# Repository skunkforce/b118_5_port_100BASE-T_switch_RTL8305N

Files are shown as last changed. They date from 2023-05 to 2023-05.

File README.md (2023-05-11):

# edgy_board number b118
This design is part of the [edgy board project](https://github.com/skunkforce/edgy_boards). It provides a cheap 5 port 100BASE-T switch.

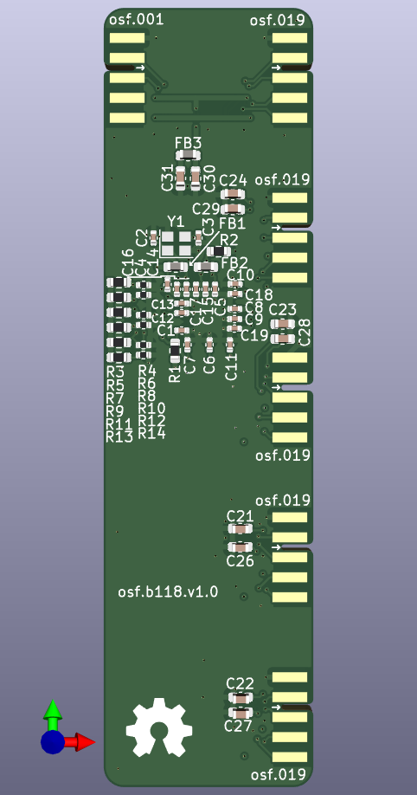
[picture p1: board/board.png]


# getting started
This repository uses submodules. After cloning use the command 

```$ git submodule update --init --recursive```

to pull the submodules before opening the project with kicad. 

# Tests
Tests can be found in [TESTS.md](TESTS.md)

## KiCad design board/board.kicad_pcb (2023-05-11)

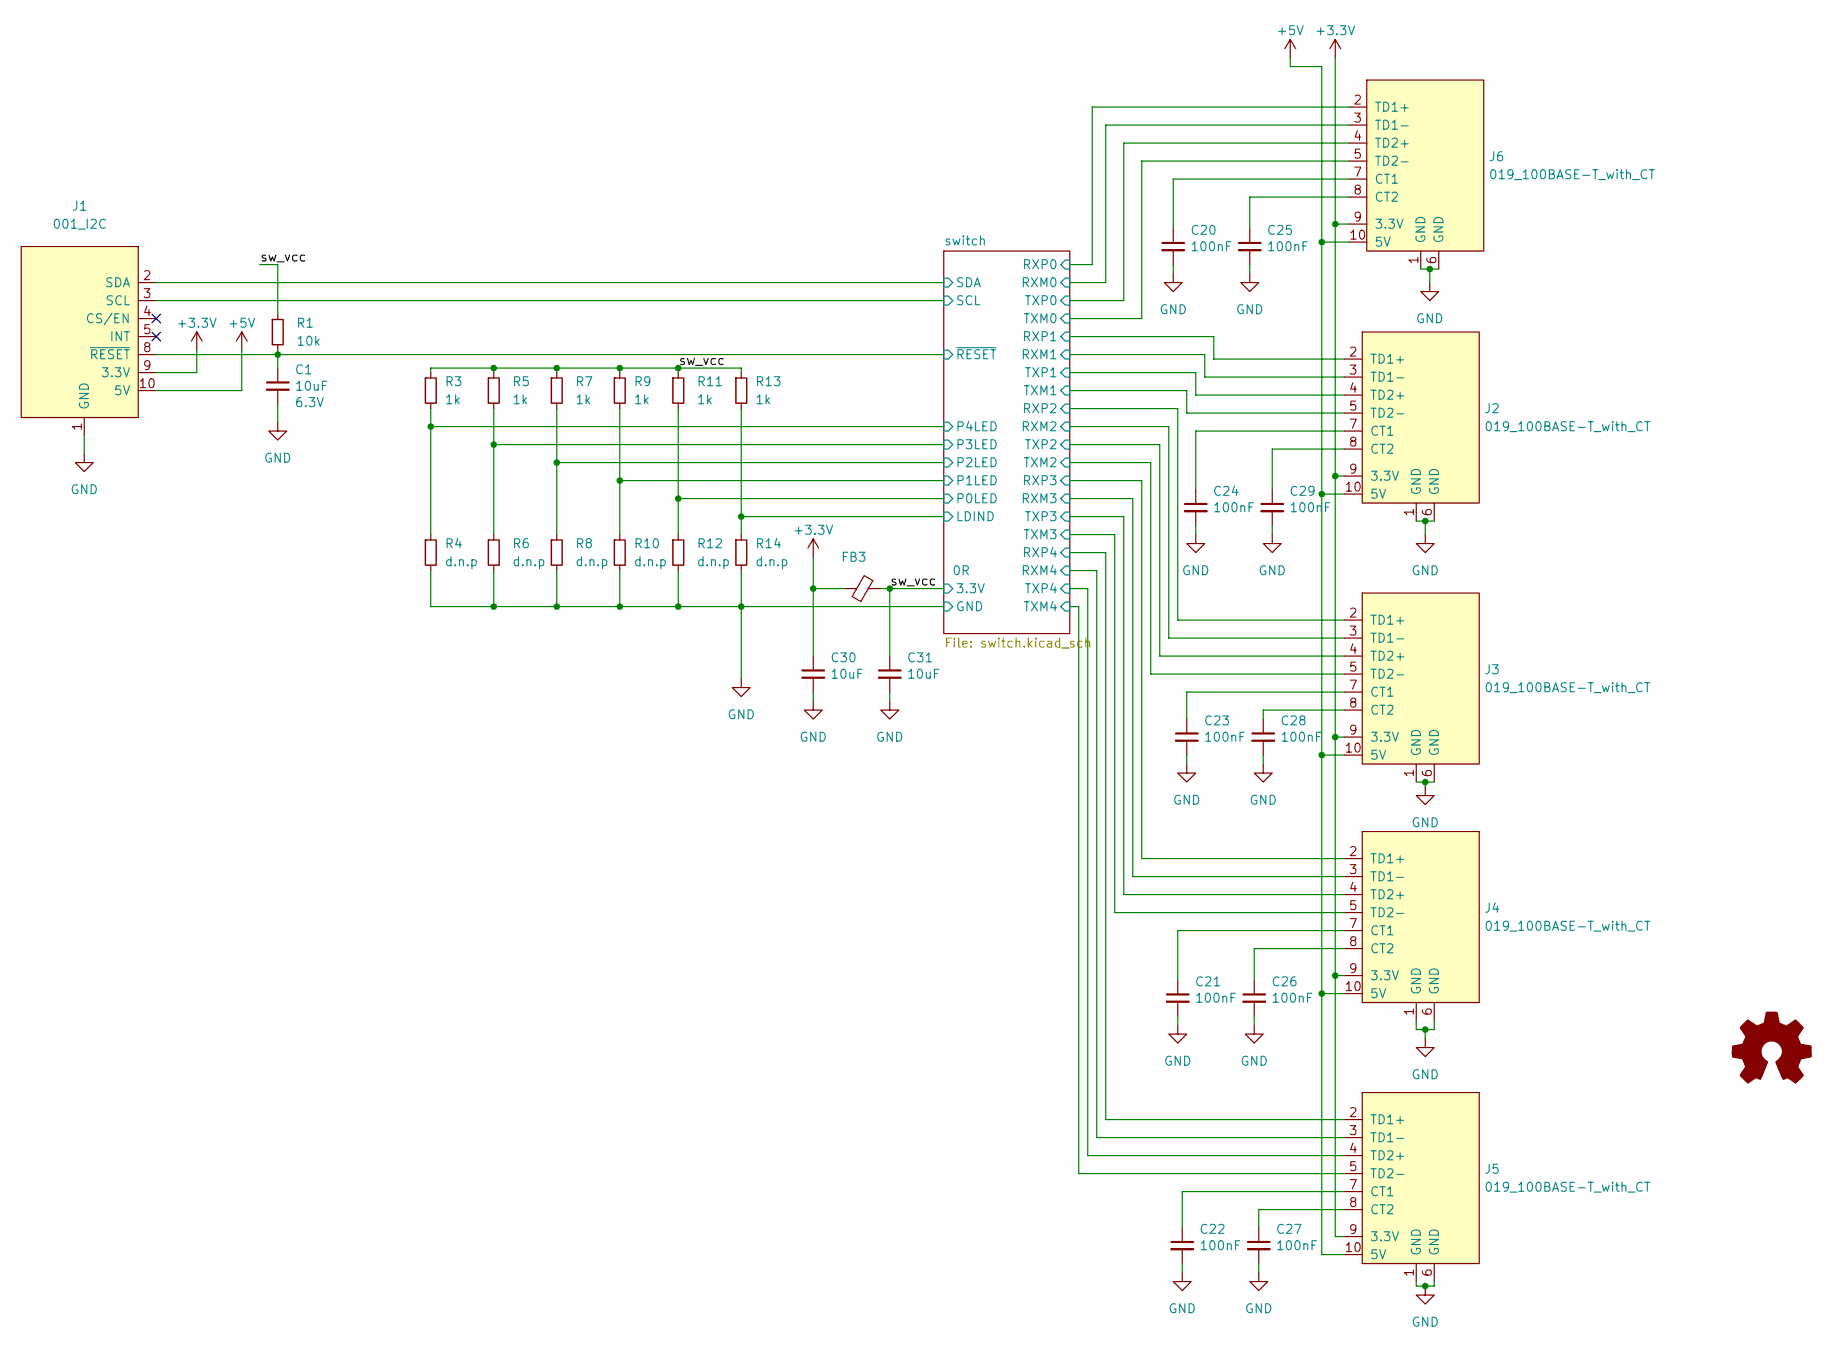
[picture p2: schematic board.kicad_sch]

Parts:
C1: 10uF; C_0402_1005Metric; Voltage 6.3V; MPN CL05A105MP5NNNC; Digi-Key_PN 1276-1448-1-ND
C20, C21, C22, C23, C24, C25, C26, C27, C28, C29: 100nF; C_0603_1608Metric
C30, C31: 10uF; C_0603_1608Metric
FB3: 0R; L_0603_1608Metric; MPN 74279228111
J1: 001_I2C; on_edge_2x05_device
J2, J3, J4, J5, J6: 019_100BASE-T_with_CT; on_edge_2x05_host
LOGO1: Logo_Open_Hardware_Small; OSHW-Symbol_6.7x6mm_SilkScreen
R1: 10k; R_0603_1608Metric
R3, R5, R7, R9, R11, R13: 1k; R_0603_1608Metric
R4, R6, R8, R10, R12, R14: d.n.p; R_0402_1005Metric

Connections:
+3.3V: C30.1, FB3.1, J1.9 (3.3V), J2.9 (3.3V), J3.9 (3.3V), J4.9 (3.3V), J5.9 (3.3V), J6.9 (3.3V)
+5V: J1.10 (5V), J2.10 (5V), J3.10 (5V), J4.10 (5V), J5.10 (5V), J6.10 (5V)
/sw_vcc: C31.1, FB3.2, R1.1, R3.1, R5.1, R7.1, R9.1, R11.1, R13.1; also elsewhere on the board
/switch/LDIND: R13.2, R14.1; also elsewhere on the board
/switch/P0LED: R11.2, R12.1; also elsewhere on the board
/switch/P1LED: R9.2, R10.1; also elsewhere on the board
/switch/P2LED: R7.2, R8.1; also elsewhere on the board
/switch/P3LED: R5.2, R6.1; also elsewhere on the board
/switch/P4LED: R3.2, R4.1; also elsewhere on the board
/switch/RXM0: J6.3 (TD1-); also elsewhere on the board
/switch/RXM1: J2.3 (TD1-); also elsewhere on the board
/switch/RXM2: J3.3 (TD1-); also elsewhere on the board
/switch/RXM3: J4.3 (TD1-); also elsewhere on the board
/switch/RXM4: J5.3 (TD1-); also elsewhere on the board
/switch/RXP0: J6.2 (TD1+); also elsewhere on the board
/switch/RXP1: J2.2 (TD1+); also elsewhere on the board
/switch/RXP2: J3.2 (TD1+); also elsewhere on the board
/switch/RXP3: J4.2 (TD1+); also elsewhere on the board
/switch/RXP4: J5.2 (TD1+); also elsewhere on the board
/switch/SCL: J1.3 (SCL); also elsewhere on the board
/switch/SDA: J1.2 (SDA); also elsewhere on the board
/switch/TXM0: J6.5 (TD2-); also elsewhere on the board
/switch/TXM1: J2.5 (TD2-); also elsewhere on the board
/switch/TXM2: J3.5 (TD2-); also elsewhere on the board
/switch/TXM3: J4.5 (TD2-); also elsewhere on the board
/switch/TXM4: J5.5 (TD2-); also elsewhere on the board
/switch/TXP0: J6.4 (TD2+); also elsewhere on the board
/switch/TXP1: J2.4 (TD2+); also elsewhere on the board
/switch/TXP2: J3.4 (TD2+); also elsewhere on the board
/switch/TXP3: J4.4 (TD2+); also elsewhere on the board
/switch/TXP4: J5.4 (TD2+); also elsewhere on the board
/switch/~RESET: C1.1, J1.8 (~RESET), R1.2; also elsewhere on the board
GND: C1.2, C20.2, C21.2, C22.2, C23.2, C24.2, C25.2, C26.2, C27.2, C28.2, C29.2, C30.2, C31.2, J1.1 (GND), J2.1 (GND), J2.6 (GND), J3.1 (GND), J3.6 (GND), J4.1 (GND), J4.6 (GND), J5.1 (GND), J5.6 (GND), J6.1 (GND), J6.6 (GND), R4.2, R6.2, R8.2, R10.2, R12.2, R14.2; also elsewhere on the board
unnamed: C20.1, J6.7 (CT1)
unnamed: C21.1, J4.7 (CT1)
unnamed: C22.1, J5.7 (CT1)
unnamed: C23.1, J3.7 (CT1)
unnamed: C24.1, J2.7 (CT1)
unnamed: C25.1, J6.8 (CT2)
unnamed: C26.1, J4.8 (CT2)
unnamed: C27.1, J5.8 (CT2)
unnamed: C28.1, J3.8 (CT2)
unnamed: C29.1, J2.8 (CT2)

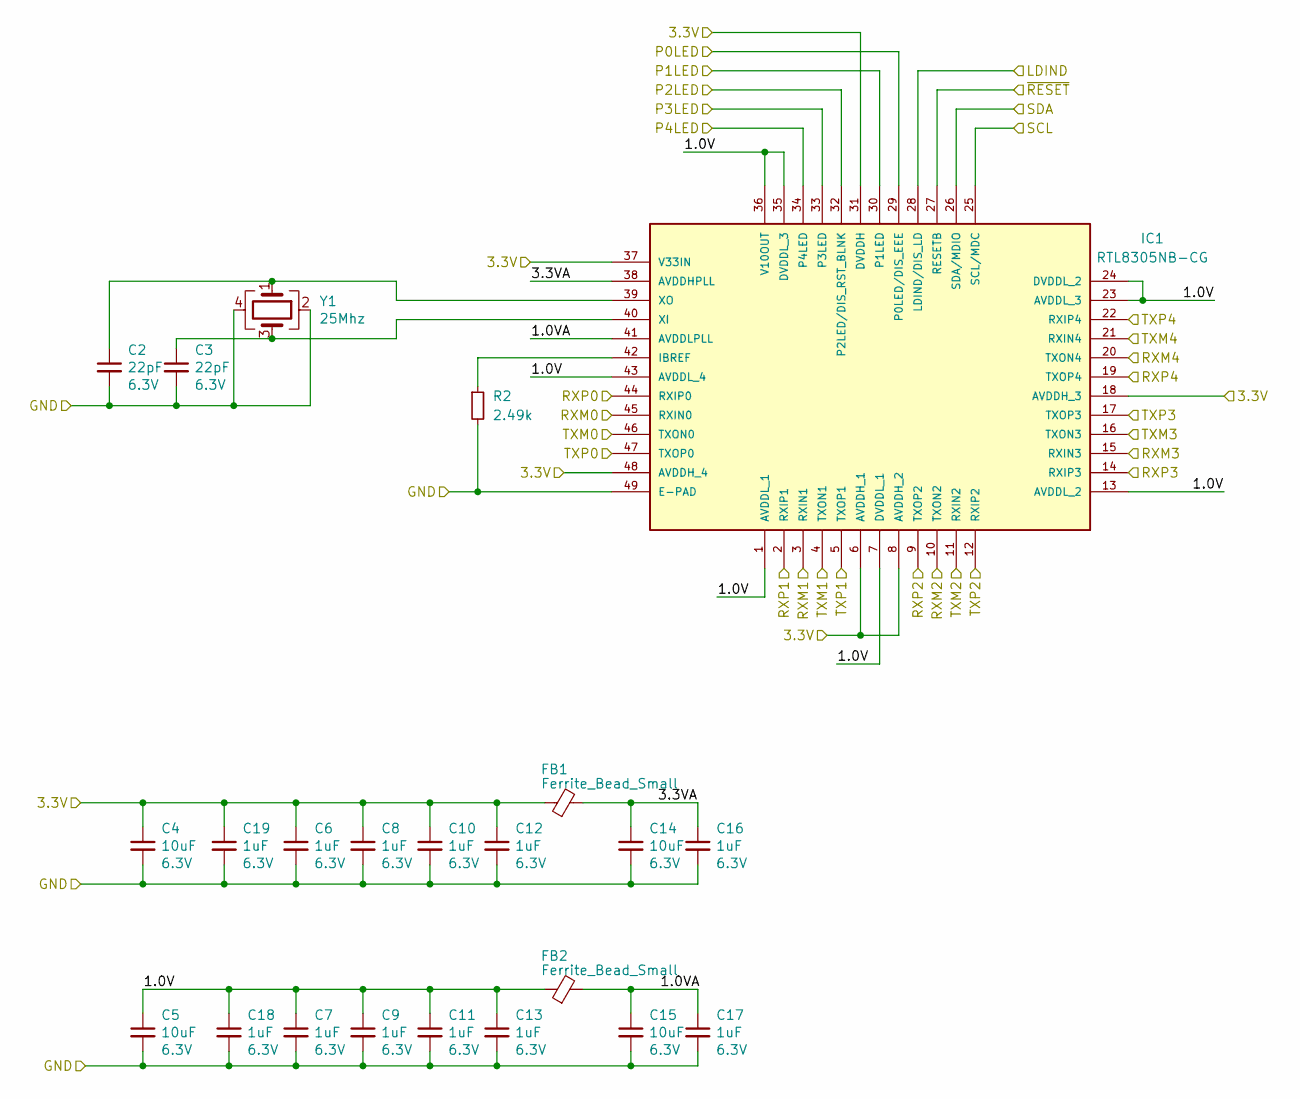
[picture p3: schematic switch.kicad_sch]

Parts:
C2, C3: 22pF; C_0402_1005Metric; Voltage 6.3V; Digi-Key_PN 1276-1665-1-ND
C4, C5, C14, C15: 10uF; C_0402_1005Metric; Voltage 6.3V; MPN CL05A105MP5NNNC; Digi-Key_PN 1276-1448-1-ND
C6, C7, C8, C9, C10, C11, C12, C13, C16, C17, C18, C19: 1uF; C_0402_1005Metric; Voltage 6.3V; MPN CL05A105MP5NNNC; Digi-Key_PN 1276-1448-1-ND
FB1, FB2: Ferrite_Bead_Small; L_0603_1608Metric; MPN 74279228111
IC1: RTL8305NB-CG; QFN40PEDITED
R2: 2.49k; R_0603_1608Metric
Y1: 25Mhz; Crystal_SMD_2520-4Pin_2.5x2.0mm; MPN ECS-250-18-36B-CKY-TR

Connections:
/sw_vcc: C4.1, C6.1, C8.1, C10.1, C12.1, C19.1, FB1.1, IC1.6 (AVDDH_1), IC1.8 (AVDDH_2), IC1.18 (AVDDH_3), IC1.31 (DVDDH), IC1.37 (V33IN), IC1.48 (AVDDH_4); also elsewhere on the board
/switch/1.0V: C5.1, C7.1, C9.1, C11.1, C13.1, C18.1, FB2.1, IC1.1 (AVDDL_1), IC1.7 (DVDDL_1), IC1.13 (AVDDL_2), IC1.23 (AVDDL_3), IC1.24 (DVDDL_2), IC1.35 (DVDDL_3), IC1.36 (V10OUT), IC1.43 (AVDDL_4)
/switch/1.0VA: C15.1, C17.1, FB2.2, IC1.41 (AVDDLPLL)
/switch/3.3VA: C14.1, C16.1, FB1.2, IC1.38 (AVDDHPLL)
/switch/LDIND: IC1.28 (LDIND/DIS_LD); also elsewhere on the board
/switch/P0LED: IC1.29 (P0LED/DIS_EEE); also elsewhere on the board
/switch/P1LED: IC1.30 (P1LED); also elsewhere on the board
/switch/P2LED: IC1.32 (P2LED/DIS_RST_BLNK); also elsewhere on the board
/switch/P3LED: IC1.33 (P3LED); also elsewhere on the board
/switch/P4LED: IC1.34 (P4LED); also elsewhere on the board
/switch/RXM0: IC1.45 (RXIN0); also elsewhere on the board
/switch/RXM1: IC1.3 (RXIN1); also elsewhere on the board
/switch/RXM2: IC1.10 (TXON2); also elsewhere on the board
/switch/RXM3: IC1.15 (RXIN3); also elsewhere on the board
/switch/RXM4: IC1.20 (TXON4); also elsewhere on the board
/switch/RXP0: IC1.44 (RXIP0); also elsewhere on the board
/switch/RXP1: IC1.2 (RXIP1); also elsewhere on the board
/switch/RXP2: IC1.9 (TXOP2); also elsewhere on the board
/switch/RXP3: IC1.14 (RXIP3); also elsewhere on the board
/switch/RXP4: IC1.19 (TXOP4); also elsewhere on the board
/switch/SCL: IC1.25 (SCL/MDC); also elsewhere on the board
/switch/SDA: IC1.26 (SDA/MDIO); also elsewhere on the board
/switch/TXM0: IC1.46 (TXON0); also elsewhere on the board
/switch/TXM1: IC1.4 (TXON1); also elsewhere on the board
/switch/TXM2: IC1.11 (RXIN2); also elsewhere on the board
/switch/TXM3: IC1.16 (TXON3); also elsewhere on the board
/switch/TXM4: IC1.21 (RXIN4); also elsewhere on the board
/switch/TXP0: IC1.47 (TXOP0); also elsewhere on the board
/switch/TXP1: IC1.5 (TXOP1); also elsewhere on the board
/switch/TXP2: IC1.12 (RXIP2); also elsewhere on the board
/switch/TXP3: IC1.17 (TXOP3); also elsewhere on the board
/switch/TXP4: IC1.22 (RXIP4); also elsewhere on the board
/switch/~RESET: IC1.27 (RESETB); also elsewhere on the board
GND: C2.2, C3.2, C4.2, C5.2, C6.2, C7.2, C8.2, C9.2, C10.2, C11.2, C12.2, C13.2, C14.2, C15.2, C16.2, C17.2, C18.2, C19.2, IC1.49 (E-PAD), R2.2, Y1.2, Y1.4; also elsewhere on the board
unnamed: C2.1, IC1.39 (XO), Y1.1
unnamed: C3.1, IC1.40 (XI), Y1.3
unnamed: IC1.42 (IBREF), R2.1

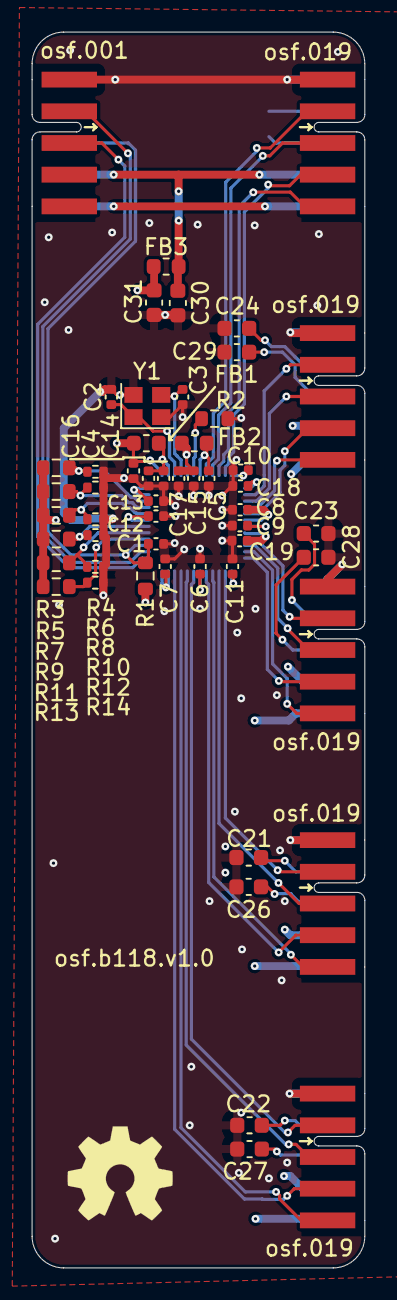
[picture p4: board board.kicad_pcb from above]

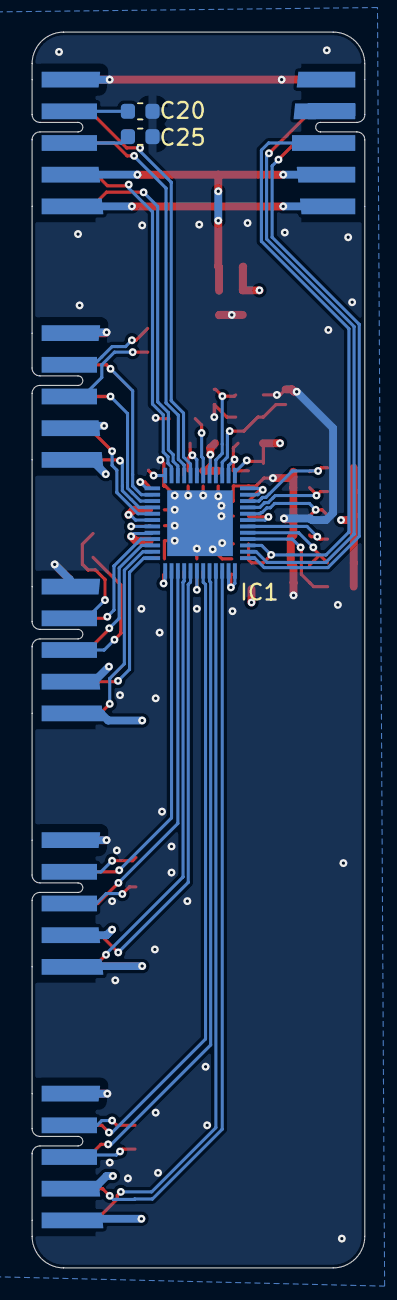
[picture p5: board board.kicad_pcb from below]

Board: 4 copper layers, 21.0 x 78.0 mm, 57 parts (3 on the bottom side), 49 nets.

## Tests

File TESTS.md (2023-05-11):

# communication test
## setup
Connected usb -> b051 -> b103 -> b118 for power and b118 -> b004 -> ethernet 2x and tested communication between them. 
## results
fast communication was possible.

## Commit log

2023-03-29 added decoupling
    [board.kicad_pcb, board.kicad_sch]
2023-03-30 added N filter for 3.3V input
    [board.kicad_pcb, board.kicad_sch]
